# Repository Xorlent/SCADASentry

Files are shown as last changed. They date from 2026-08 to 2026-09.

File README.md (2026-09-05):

## SCADASentry - SCADA PLC Network Monitoring for the Rest of Us
### Ultra low-cost, no maintenance, purpose-built Allen Bradley ControlLogix PLC network and vulnerability monitor ###

> [!WARNING]
> _USE AT YOUR OWN RISK._  This solution is not recommended where a malfunction could carry injury, life, or financial risk.
> 
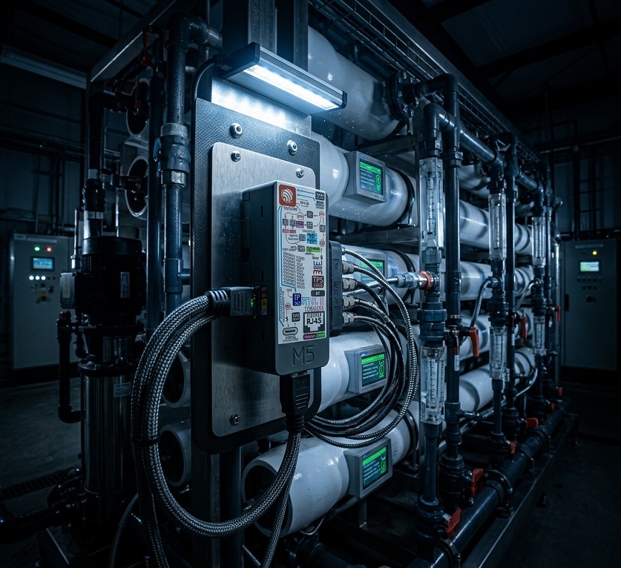
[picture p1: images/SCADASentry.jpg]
SCADASentry Sensor Image


## Table of Contents
- [Background](#background)
- [Features](#features)
- [Requirements](#requirements)
- [Functional Description](#functional-description)
  - [Activity monitoring](#activity-monitoring)
  - [EtherNet/IP monitoring](#ethernetip-monitoring)
  - [LAN device discovery](#lan-device-discovery)
  - [Minimizing PLC impact](#minimizing-plc-impact)
  - [Internet and DHCP detection](#internet-and-dhcp-detection)
- [Firmware Vulnerability Lookup](#firmware-vulnerability-lookup)
  - [How it works](#how-it-works)
  - [TXT record format](#txt-record-format)
  - [Example DNS TXT records](#example-dns-txt-records)
  - [Result](#result)
  - [When it runs](#when-it-runs)
- [Programming](#programming)
  - [Prepare configuration details for your device](#prepare-configuration-details-for-your-device)
  - [Configure and flash the device](#configure-and-flash-the-device)
- [SNMP Trap Reference](#snmp-trap-reference)
  - [LAN device discovery traps](#lan-device-discovery-traps)
  - [Device object varbinds](#device-object-varbinds)
  - [Enumerated varbinds (translated by the MIB)](#enumerated-varbinds-translated-by-the-mib)
- [Guidance and Notes](#guidance-and-notes)
- [Installation Options](#installation-options)
- [Technical Information](#technical-information)

## Background
Commercial OT/SCADA vulnerability and monitoring platforms are expensive to license, time-consuming to stand up, and finicky to keep running - and once they are running they tend to flood operators with unnecessary notifications that cause alert fatigue. For many, the cost and operational overhead can be hard to justify, especially in smaller environments.

SCADASentry takes a different approach. It is a purpose-built, ultra low-cost (~$21.50 in hardware), zero-maintenance device that plugs into a PoE port and quietly watches your PLC LAN. It reports only the events that matter: new or departed devices, run-key and firmware changes, and scanning/reconnaissance activity - All via standard SNMP traps or email.  No servers, specialized network appliances, span ports, agent software, cloud dependency, and no tuning required.

This device was designed specifically for monitoring Allen Bradley ControlLogix PLC network environments and is intentionally simple.  If detailed device activity (tag create/delete, program load, etc.) is needed, a commercial OT/SCADA platform is likely the better choice.

## Features
- **Passive honeypot monitoring**:
  Listens on any number of user-configurable TCP/UDP ports and ICMP types and reports every unexpected connection, revealing scanning, reconnaissance, and lateral movement that traditional tools miss.
- **EtherNet/IP discovery detection**:
  Watches UDP ports 44818 and 2222 for RSLogix/RSLinx browse traffic, flagging unauthorized devices attempting to discover and interact with your ControlLogix PLCs.
- **LAN device inventory**:
  Uses ARP to detect every device that joins or leaves the PLC network and identifies ControlLogix PLCs (vendor, firmware, serial, state, run-switch mode), so unapproved hardware is immediately visible.
- **Run-switch & firmware change alerts**:
  Continuously re-checks each PLC's run/remote/program mode and firmware revision and alerts on any change, so you immediately notice if a controller was left out of RUN after maintenance or a module was missed during a firmware update sweep.
- **Firmware vulnerability lookup**:
  Cross-references each CPU and communication module's firmware against DNS TXT records to flag controllers running firmware with known CVEs before they can be exploited.
- **Rogue DHCP / Internet detection**:
  Flags unexpected DHCP servers or Internet reachability on the PLC network, exposing rogue devices or a dangerous bridge between your OT network and the outside world.
- **Minimal PLC impact**:
  Sweeps with throttled ARP (never ICMP) and queries only the data it needs, keeping its footprint on the network and on production controllers as small as possible.
- **No-nonsense alerting**:
  Reports only the events that matter via standard SNMPv2c traps or email, integrating with your existing systems and reducing alert fatigue.
- **Ultra low-cost & zero-maintenance**:
  A ~$21.50 PoE device requiring no servers, span ports, agent software, cloud dependency, or tuning, making enterprise-grade OT monitoring practical even for smaller environments.

## Requirements
1. M5Stack [Unit-PoE-P4](https://shop.m5stack.com/products/unit-poe-with-esp32-p4), currently $21.50 USD
2. PoE network port or PoE power injector or a USB charger to power the device once deployed
3. USB-C cable for programming
4. An SNMP trap receiver (NMS such as PRTG) or an available SMTP relay
5. An accessible NTP server for time synchronization

## Functional Description
SCADASentry is a honeypot that listens on any number of user-configurable TCP and UDP ports and reports activity via **SNMPv2c traps** (or email via SMTP). It detects devices joining and leaving the local PLC LAN, alerts on scanning, reconnaissance, and lateral movement, and reports basic ControlLogix device information - notifying on run-key or firmware version changes.

### Activity monitoring
When unexpected activity is detected, the device immediately sends a trap or email containing the source IP, protocol, destination port (or ICMP type), and service name. The following events are reported:

| Event | Trap |
|---|---|
| TCP connection on a monitored port | `tcpConnectionTrap` |
| UDP packet on a monitored port | `udpConnectionTrap` |
| ICMP request of a monitored type | `icmpRequestTrap` |
| Fragmented IP packet (suspicious) | `ipFragmentTrap` |
| IP packet with options (suspicious) | `ipOptionsTrap` |
| Device comes online (boot or link recovery) | `deviceOnlineTrap` |

The device sends a `deviceOnlineTrap` when it boots (power recovery) or when its Ethernet link recovers, with a `honeypotStartReason` varbind distinguishing the cause (`powerOn` vs `linkUp`). It can also be configured to alert on ICMP ping requests (note: it will not respond to pings when ICMP monitoring is enabled).

### EtherNet/IP monitoring
For Rockwell Automation / EtherNet/IP broadcast traffic, the device listens on UDP ports **44818** and **2222** and reports only `ListIdentity` browse/discovery traffic, silently ignoring device I/O data. This detects RSLogix/RSLinx device browsing activity from unauthorized devices.

### LAN device discovery
The device periodically scans the local LAN using ARP to discover devices. For each discovered device it:

- Identifies ControlLogix PLCs via an EtherNet/IP `ListIdentity` broadcast, then queries them over TCP 44818 for identity, firmware, serial, state, and run-switch mode.
- Probes hosts that do not answer the `ListIdentity` broadcast directly on TCP 44818, so PLCs that suppress discovery responses are still identified.
- Reports newly discovered devices via `newDeviceDiscoveredTrap`, including the MAC address and the vendor, product name, firmware, serial, state, and run-switch mode if it is a PLC.
- Reports devices that stop responding via `deviceDisappearedTrap`. A departed device is detected only after its ARP entry expires, so this trap can lag a device's actual departure by up to 5 minutes.
- Re-checks the run-switch mode and firmware version of discovered PLCs periodically (configurable), reporting changes via `deviceModeChangedTrap` / `deviceFirmwareChangedTrap`.
- Enumerates the CPU and any Ethernet modules in the rack (including redundant/secondary CPUs) and derives an Advisory CVE search URL for each module.

### Minimizing PLC impact
SCADASentry is designed to be a passive observer of production PLCs, so it goes out of its way to avoid disturbing the controllers it monitors.

**No ICMP traffic.** Device discovery does not use ICMP echo requests (ping). Instead, the device sweeps the local subnet with ARP requests (`etharp_request`), which are answered by the network interface at the link layer and never touch a PLC's IP stack or CPU the way an ICMP echo would. Each host is probed with a single ARP request, and requests are throttled between hosts (`LAN_SCAN_ARP_THROTTLE_MS` in Config.h) to keep the scan's impact on the segment low.

**Only the data we need.** When querying a discovered PLC, the device reads only the CIP Identity object - product name, firmware revision, keyswitch position, serial number, and state - plus the Identity of each CPU and Ethernet module in the rack. Backplane slots are probed only up to the highest slot previously detected on each PLC, with a periodic full re-probe to catch modules added to higher slots (`SLOT_EXPANSION_CHECK_MULTIPLIER` in Config.h).

### Internet and DHCP detection
The device periodically probes the local LAN for a DHCP server and verifies Internet reachability:

- It retrieves the DHCP server identifier and the advertised default gateway, then tests Internet reachability through that gateway and/or the configured default gateway (a TCP connection to a public anycast IP on port 443, falling back to a DNS query to a public resolver).
- When Internet access is detected, it reports `internetDetectedTrap`, including the gateway and any DHCP server found.
- The DHCP probe sends only a DHCPDISCOVER, so it does not obtain or reserve an IP address - the device always keeps its statically-configured IP.
- If a DHCP server advertises a default gateway outside the device's configured subnet, the device treats it as a rogue DHCP server: it skips testing that gateway and reports `rogueDhcpServerTrap` (including the rogue server IP and the advertised gateway) instead.

## Firmware Vulnerability Lookup
SCADASentry can determine whether a discovered ControlLogix CPU or Ethernet module is running firmware with known vulnerabilities. It uses DNS TXT records, so it works using your own DNS infrastructure in a disconnected environment.

### How it works
1. For each module, the device extracts the full catalog suffix from the product name (e.g. `1756-EN2T/B` -> `EN2T/B`, `1756-L55/A` -> `L55/A`) and converts it to a valid DNS label (`/` becomes `-`, e.g. `EN2T/B` -> `EN2T-B`).
2. It prepends that label to `vulnSearchSuffix` (Config.h) to form the TXT record name, e.g. `EN2T-B.vuln.plc.local`.
3. It queries the configured DNS servers (`dns1`, then `dns2`) for a TXT record at that name.

### TXT record format
The TXT value is the **minimum firmware revision that is _not_ vulnerable**, formatted `major.minor` (e.g. `11.2`), or the literal string `EOL` (case-insensitive) for end-of-life products. For example, `EN2T-B.vuln.plc.local  TXT  "11.2"` marks any `1756-EN2T/B` running firmware older than `11.2` as vulnerable.

### Example DNS TXT records
The TXT record name is the module's full catalog suffix (with `/` replaced by `-`) prepended to `vulnSearchSuffix` in Config.h. For example, a `1756-EN2T/D` module (`EN2T/D` -> `EN2T-D`) with `vulnSearchSuffix = "vuln.plc.local"` resolves `EN2T-D.vuln.plc.local`. For CPUs whose product name has no catalog prefix (e.g. `ControlLogix 5580 Controller`), the short search term (`5580`) is used instead.

Starter records (the value is the minimum non-vulnerable firmware, or `EOL`):

| Label | TXT value | Module |
|---|---|---|
| `5580` | `37.013` | ControlLogix 5580 CPU |
| `L55-A` | `EOL` | 1756-L55 |
| `ENBT-A` | `EOL` | 1756-ENBT |
| `EN2T-A` | `EOL` | 1756-EN2T |
| `EN2T-B` | `EOL` | 1756-EN2T |
| `EN2T-C` | `EOL` | 1756-EN2T |
| `EN2T-D` | `12.002` | 1756-EN2T |
| `EN2F-A` | `EOL` | 1756-EN2F |
| `EN2F-B` | `EOL` | 1756-EN2F |
| `EN2F-C` | `12.002` | 1756-EN2F |
| `EN3TR-A` | `EOL` | 1756-EN3TR |
| `EN3TR-B` | `12.002` | 1756-EN3TR |
| `EN3TR-C` | `12.002` | 1756-EN3TR |

Each record's full name is `<label>.<vulnSearchSuffix>` (e.g. `EN2T-D.vuln.plc.local`). In a zone file:

```
EN2T-D.vuln.plc.local.  IN  TXT  "12.002"
L55-A.vuln.plc.local.   IN  TXT  "EOL"
```
Windows DNS Server example:  
[DNS Vulnerability DB](https://github.com/Xorlent/SCADASentry/blob/main/images/DNSVulnerabilityDB.png)
### Result
Each module is marked `YES` (vulnerable), `NO` (not vulnerable), or `N/A` (could not be determined):
- `YES` - firmware is below the published threshold, or the record is `EOL`.
- `NO` - firmware is at or above the published threshold.
- `N/A` - the DNS server was unreachable, or the feature is disabled (empty `vulnSearchSuffix` in Config.h).

When a lookup cannot be completed (no TXT record, DNS timeout, or an unparseable value), the module is conservatively treated as **vulnerable**.

### When it runs
- DNS availability is checked at the start of every LAN scan.
- Vulnerability status is evaluated when a device is first discovered and re-evaluated on every status check (`LAN_STATUS_CHECK_MULTIPLIER` in Config.h, default hourly), so newly published firmware TXT records are picked up automatically.

The per-module vulnerability status is reflected in email alerts - the firmware version is color-coded (green = `NO`, red = `YES`, black = `N/A`) and firmware-change emails use an `ALERT` subject when vulnerable, otherwise `Notice`. The status is also held in memory, like the advisory search URL.

## Programming
### Prepare configuration details for your device:  
- Host name
- Device IP address, gateway, and subnet mask
- Local DNS servers (recommended)
- Vulnerability lookup DNS search suffix (recommended)
- SNMP trap receiver IP and community string if email (USE_SMTP) is _false_ (default)
- Email to, from addresses, and SMTP relay IP if email (USE_SMTP) is _true_
- List of IP addresses (`excludedHosts` in Config.h) to exclude from the LAN scan and from honeypot alerting (traffic from these IPs does not generate alerts)
  - Example: RSLinx/FactoryTalk PC
- List of PLC IP addresses (`excludedPLCs` in Config.h) to exclude from ARP and EtherNet/IP discovery (these PLCs are not probed and not reported, even if they answer the `ListIdentity` broadcast)
- NTP server (required)
- TCP and/or UDP ports to listen on (defaults are recommended)
- LAN scan interval, slot expansion check interval, and hosts excluded from network scans (defaults are recommended)
### Configure and flash the device:
_Once you've successfully programmed a single unit, skip steps 1 & 2.  Repeating this process takes 3 minutes from start to finish._  
1. [Set up your Arduino programming environment](https://github.com/Xorlent/SCADASentry/blob/main/ARDUINO-SETUP.md)
2. In Arduino, open the project file (SCADASentry.ino)
   - Select Tools->Board->esp32 and select "ESP32P4 Dev Module"
   - Configure board settings according to the [Unit-PoE-P4 Board Configuration](https://github.com/Xorlent/SCADASentry/blob/main/images/ESP32P4-Config.jpg)
3. Connect the Unit-PoE-P4 to your computer via USB
   - Select Tools->Port and select the device port
     - If you're unsure, unplug the device, look at the port list, then plug it back in and select the new entry
> [!WARNING]
> Do not plug the device into a PoE-powered Ethernet port until after step 6 or you risk damaging your USB port!
4. In Arduino
   - Edit Config.h with configuration details you have collected for the device
   - Select Sketch->Upload to flash the device
   - When you see something similar to the following, proceed to step 5
```
Writing at 0x000f4830 [==============================] 100.0% 495157/495157 bytes... 
Wrote 935984 bytes (495157 compressed) at 0x00010000 in 3.6 seconds (2098.6 kbit/s).
Hash of data verified.

Hard resetting via RTS pin...
```
5. In Arduino
   - Select Tools->Serial Monitor
   - Address any configuration errors or warnings shown in the serial console
     - If you did not immediately open the serial monitor, you may need to re-connect the device to see the configuration check output
6. When configuration is complete, disconnect the USB cable
7. Connect the device to a PoE network port and mount as appropriate
8. If using SNMP (versus SMTP), configure your SNMP trap alerts:
    - Import SCADASENTRY-MIB.mib into your NMS to resolve trap OIDs to human-readable names
    - Add alert triggers based on traps received from the device to get immediate notice of potential scanning and lateral movement
    - Example trap for IP 10.70.103.12 connecting to TCP port 443:
      - Trap OID: 1.3.6.1.4.1.99999.0.1 (tcpConnectionTrap)
      - Varbinds: honeypotSourceIp=10.70.103.12, honeypotProtocol=6, honeypotDestPort=443, honeypotServiceName="https", honeypotEventTime="2026-08-16T21:12:52Z"
    - Example trap for IP 10.70.103.12 connecting to UDP port 137:
      - Trap OID: 1.3.6.1.4.1.99999.0.2 (udpConnectionTrap)
      - Varbinds: honeypotSourceIp=10.70.103.12, honeypotProtocol=17, honeypotDestPort=137, honeypotServiceName="netbios-ns"
    - Example trap for IP 10.70.103.12 sending a ping request to the honeypot:
      - Trap OID: 1.3.6.1.4.1.99999.0.3 (icmpRequestTrap)
      - Varbinds: honeypotSourceIp=10.70.103.12, honeypotProtocol=1, honeypotIcmpType=8, honeypotServiceName="echo-request"
## SNMP Trap Reference
All traps are SNMPv2c, sent to UDP port 162 (configurable). Import `SCADASENTRY-MIB.mib` into your NMS to resolve OIDs to human-readable names and translate enumerated values.

| Trap | OID | Varbinds |
|---|-----|---|
| `tcpConnectionTrap` | `1.3.6.1.4.1.99999.0.1` | eventTime, sourceIp, protocol, destPort, serviceName |
| `udpConnectionTrap` | `1.3.6.1.4.1.99999.0.2` | eventTime, sourceIp, protocol, destPort, serviceName |
| `icmpRequestTrap` | `1.3.6.1.4.1.99999.0.3` | eventTime, sourceIp, protocol, icmpType, serviceName |
| `ipFragmentTrap` | `1.3.6.1.4.1.99999.0.4` | eventTime, sourceIp, protocol, serviceName |
| `ipOptionsTrap` | `1.3.6.1.4.1.99999.0.5` | eventTime, sourceIp, protocol, serviceName |
| `deviceOnlineTrap` | `1.3.6.1.4.1.99999.0.6` | eventTime, sourceIp, startReason |

### LAN device discovery traps

| Trap | OID | Varbinds |
|---|-----|---|
| `newDeviceDiscoveredTrap` | `1.3.6.1.4.1.99999.0.8` | eventTime, deviceIp, deviceMac, (PLC: vendor, productName, firmware, serial, state, mode, and per-module slot/type/productName/firmware) |
| `deviceDisappearedTrap` | `1.3.6.1.4.1.99999.0.9` | eventTime, deviceIp, deviceMac |
| `deviceModeChangedTrap` | `1.3.6.1.4.1.99999.0.10` | eventTime, deviceIp, deviceMac, prevMode, mode |
| `deviceFirmwareChangedTrap` | `1.3.6.1.4.1.99999.0.11` | eventTime, deviceIp, deviceMac, moduleSlot, moduleType, moduleProductName, modulePreviousFirmware, moduleFirmware |
| `internetDetectedTrap` | `1.3.6.1.4.1.99999.0.12` | eventTime, gatewayIp, dhcpServerIp, internetAccessible, detectionMethod |
| `rogueDhcpServerTrap` | `1.3.6.1.4.1.99999.0.13` | eventTime, dhcpServerIp, gatewayIp |

Every trap also carries the standard `sysUpTime.0` (TimeTicks) and `snmpTrapOID.0` varbinds.

### Device object varbinds

| OID | Name | Type |
|-----|---|---|
| `.1.6.0` | `deviceIpAddress` | IpAddress |
| `.1.7.0` | `deviceMacAddress` | OCTET STRING (6) |
| `.1.8.0` | `deviceVendor` | INTEGER (CIP vendor ID) |
| `.1.9.0` | `deviceProductName` | OCTET STRING |
| `.1.10.0` | `deviceFirmwareVersion` | OCTET STRING |
| `.1.11.0` | `deviceSerial` | OCTET STRING |
| `.1.12.0` | `deviceState` | INTEGER (enum) |
| `.1.13.0` | `deviceMode` | INTEGER (enum) |
| `.1.15.0` | `devicePreviousMode` | INTEGER (enum) |
| `.1.21.0` | `internetDhcpServerIp` | IpAddress |
| `.1.22.0` | `internetAccessible` | INTEGER (enum) |
| `.1.23.0` | `internetDetectionMethod` | INTEGER (enum) |
| `.1.24.0` | `internetGatewayIp` | IpAddress |
| `.1.25.1.1` | `moduleIndex` | INTEGER |
| `.1.25.1.2` | `moduleSlot` | INTEGER (0 = CPU) |
| `.1.25.1.3` | `moduleType` | INTEGER (enum) |
| `.1.25.1.4` | `moduleProductName` | OCTET STRING |
| `.1.25.1.5` | `moduleFirmware` | OCTET STRING |
| `.1.25.1.6` | `modulePreviousFirmware` | OCTET STRING |

### Enumerated varbinds (translated by the MIB)

- `honeypotProtocol`: `icmp(1)`, `tcp(6)`, `udp(17)`
- `honeypotStartReason`: `powerOn(1)`, `linkUp(2)`
- `honeypotIcmpType`: `ping(8)`, `pingExtended(42)`
- `deviceState`: `nonexistent(0)`, `selfTesting(1)`, `standby(2)`, `operational(3)`, `majorRecoverableFault(4)`, `majorUnrecoverableFault(5)`, `communicationFault(6)`, `unconfigured(7)`
- `deviceMode`: `program(0)`, `run(1)`, `testRemote(2)`
- `moduleType`: `cpu(14)`, `ethernet(12)`
- `internetAccessible`: `no(0)`, `yes(1)`
- `internetDetectionMethod`: `none(0)`, `tcpConnect(1)`, `dnsQuery(2)`

## Guidance and Notes
- The device produces SNMPv2c traps on UDP port 162 (community string configurable in Config.h).
- SMTP alerts require an unauthenticated SMTP relay that is configured to allow the SCADASentry device IP address.
- TCP and UDP listening ports are fully user-configurable with no constraints.
- It is recommended you exempt the SCADASentry device IP addresses in any legitimate vulnerability or network scanners to avoid triggering honeypot alerts.
- If ICMP is disabled in Config.h, the device will respond to pings from any IP address within the routable network.
- LAN device discovery scans the local subnet using ARP, so it only sees devices on the same L2 segment.
- Pressing the button on the side of the Unit-PoE-P4 for > 1 second clears all detected-device and holdoff state, restarting detection as if the device had just booted.

## Installation Options
- You can find 3D printable DIN rail and 1RU mount options [here](https://github.com/Xorlent/SCADASentry/tree/main/3DModels)

## Technical Information
- CPU and Memory
  - 360MHz dual core + 40MHz LP core RISC-V
  - 768KBytes RAM
  - 16MBytes Flash + 32MBytes PSRAM
- Operating Specifications
  - Operating temperature: 0°F (-17.7°C) to 104°F (40°C)
  - Operating humidity: 5% to 90% (RH), non-condensing
- Power Consumption
  - 6W maximum via 802.3af Power-over-Ethernet
- Ethernet
  - IP101GRI or TLK110 PHY
  - 10/100 Mbit twisted pair copper
  - IEEE 802.3af Power-over-Ethernet

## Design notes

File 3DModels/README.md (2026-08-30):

## Printable DIN Rail SCADASentry Mount
### Parts Needed
- Qty. 1.25" Paper Clamp per each 2 SCADASentry mounts (each uses one clip handle)
- Qty. 1 3mm x 10mm pan head screw
- Qty. 1 M4 flathead screw (8mm recommended, up to 12mm will work)
- Qty. 1 M4 nut
### Assembly
- Print parts in the orientation shown below; add a 4-5 mm outer brim to the DIN clip only to prevent print failure
- Place the paper clamp handle into the DIN clip part, insert into the DIN mount, and secure with the 3mm x 10mm pan head screw
- Install the DIN base in the desired orientation (vertical or horizontal), insert the M4 screw and clamp the parts together with the M4 nut
- Slide the Unit-PoE-P4 module into the base, Ethernet port first and closest to the face of the base
- Install the mount by pulling back on the clip handle and clipping the mount onto the rail, pushing in the clip to secure the module

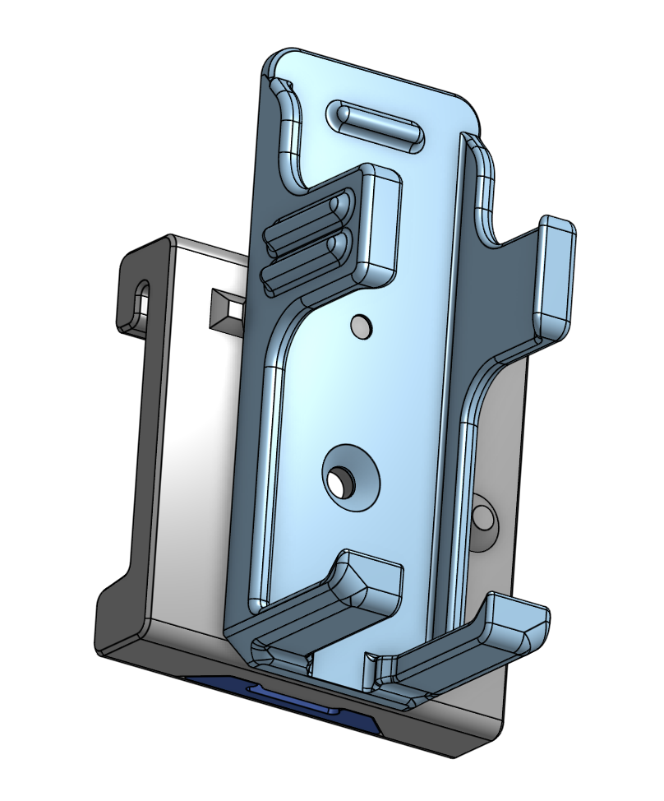
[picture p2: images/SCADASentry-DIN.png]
DIN Assembly

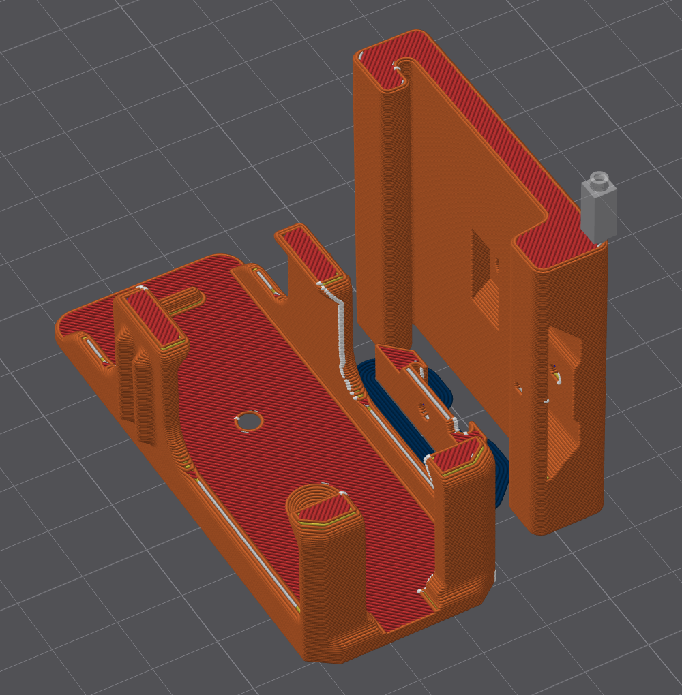
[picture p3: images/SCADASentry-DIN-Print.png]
DIN Print Orientation


## Printable 1RU Rackmount SCADASentry Base
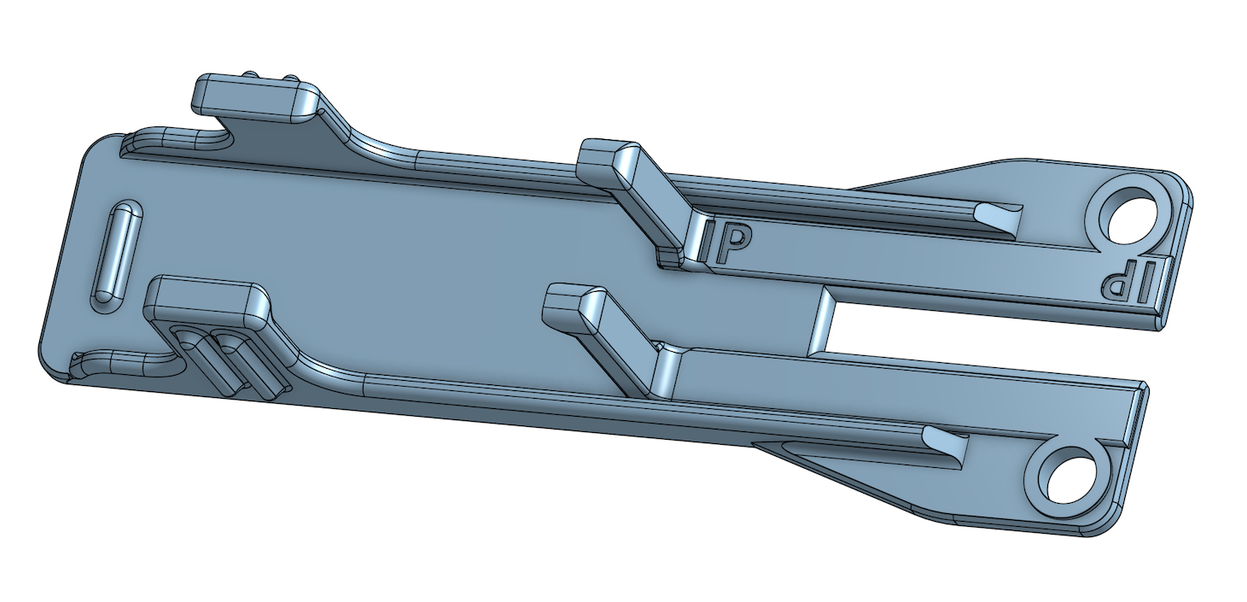
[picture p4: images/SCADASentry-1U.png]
1RU Rackmount Base Image


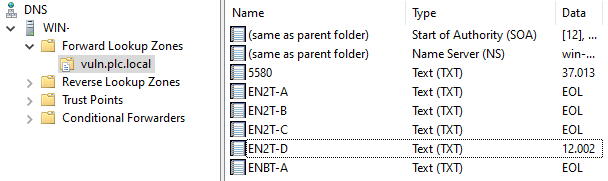
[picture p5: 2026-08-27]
images/DNSVulnerabilityDB.png

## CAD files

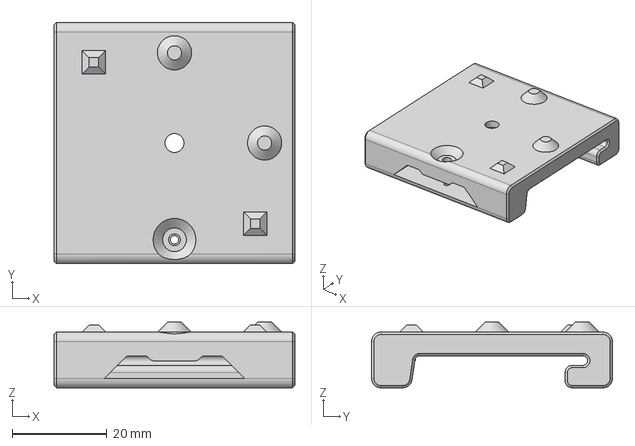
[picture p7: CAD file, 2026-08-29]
3DModels/SCADASentry-DINMount.step
50.8 x 50.8 x 13.8 mm

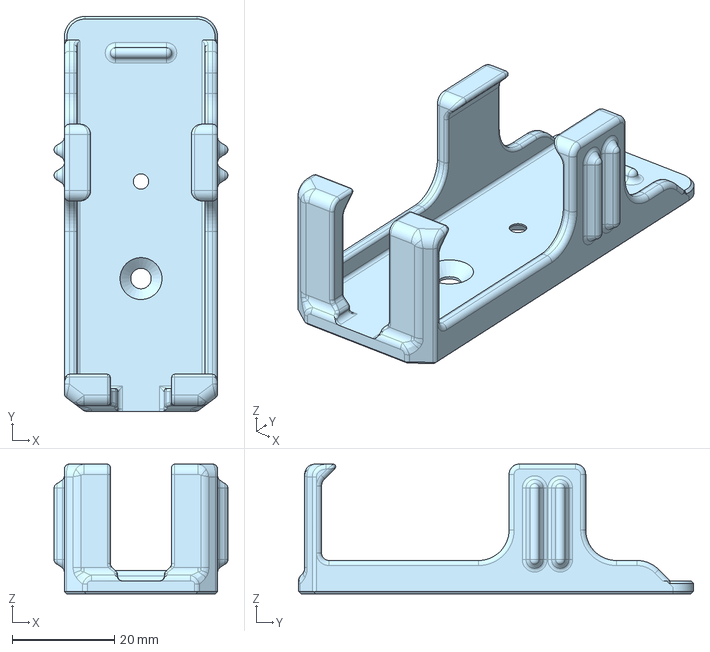
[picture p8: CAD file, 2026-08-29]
3DModels/SCADASentry-DINBase.step
34.0 x 77.3 x 25.4 mm

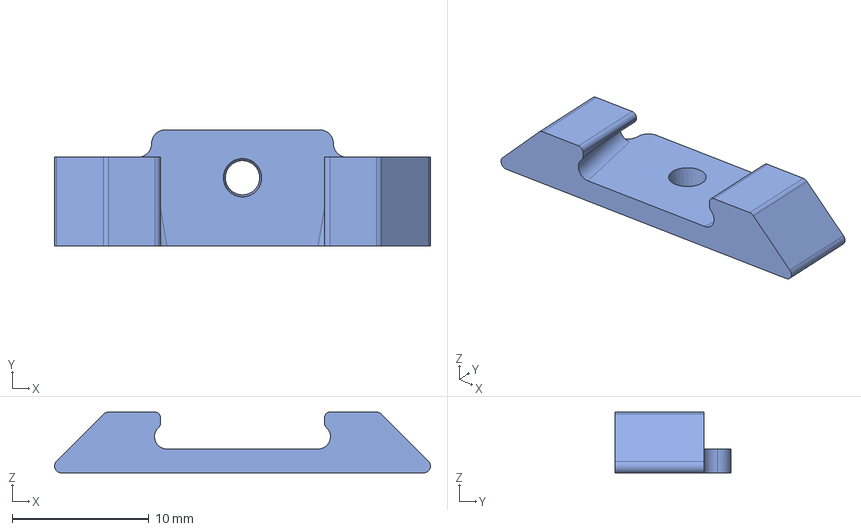
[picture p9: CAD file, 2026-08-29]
3DModels/SCADASentry-DINClip.step
27.5 x 8.50 x 4.45 mm

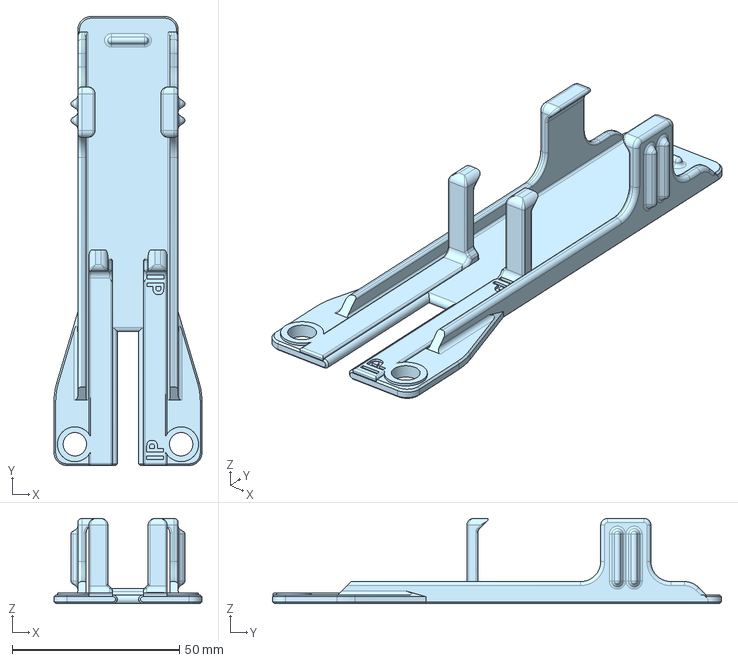
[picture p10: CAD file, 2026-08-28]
3DModels/SCADASentry-1U.step
44.2 x 134.1 x 25.4 mm

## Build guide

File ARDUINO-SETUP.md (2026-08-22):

1. Download the latest Arduino IDE appropriate for your operating system (https://www.arduino.cc/en/software)
2. Open the Arduino IDE
3. Close/save the Preferences window
4. Open the Boards Manager
   - Type "esp32" in the search field and select "esp32 by Espressif Systems" (__NOT "Arduino ESP32 Boards"__)
     - Install version 3.3.11
5. Open the Libraries Manager
   - Type "NTP" in the search field and select "NTP by Stefan Staub"
     - Install version 1.8.0

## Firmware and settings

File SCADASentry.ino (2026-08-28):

/*
 * SCADASentry.ino
 * 
 * USE AT YOUR OWN RISK. This solution is not recommended where a malfunction could carry injury, life, or financial risk.
 * 
 * GNU GENERAL PUBLIC LICENSE Version 3, 29 June 2007
 * https://github.com/Xorlent/SCADASentry
 * 
 * Raw Socket Implementation - Now monitors unlimited ports and ICMP types
 * Designed for M5Stack Unit-PoE-P4 or other device with sufficient resources
 * 
 * CONFIGURATION: All user-configurable settings are in Config.h
 * Edit Config.h to customize your honeypot deployment.
 */

#include "Config.h"

////////--------------------------------------- DO NOT EDIT ANYTHING BELOW THIS LINE ---------------------------------------////////

#include <ETH.h>
#include <WiFiUdp.h>
#include <NTP.h>
#include <lwip/ip.h>
#include <lwip/tcp.h>
#include <lwip/udp.h>
#include <lwip/icmp.h>
#include <lwip/raw.h>
#include <lwip/prot/tcp.h>
#include "HoneypotLogging.h"
#include "LanScanner.h"
#include "InternetDetection.h"
#include "ConfigValidation.h"

// Define TCP structures and flags if not already available
#ifndef TCPH_FLAGS
#define TCPH_FLAGS(phdr) (lwip_ntohs((phdr)->_hdrlen_rsvd_flags) & 0xFF)
#endif

#ifndef TCP_SYN
#define TCP_SYN   0x02U
#endif

#ifndef TCP_ACK
#define TCP_ACK   0x10U
#endif

// Map an IANA IP protocol number to the holdoff bucket (ProtocolType).
static ProtocolType protocolTypeFor(uint8_t ianaProtocol) {
  switch (ianaProtocol) {
    case IP_PROTO_UDP:  return PROTO_UDP;
    case IP_PROTO_ICMP: return PROTO_ICMP;
    case IP_PROTO_TCP:
    default:            return PROTO_TCP;
  }
}

#define ETH_ADDR        1
#define ETH_POWER_PIN   51
#define ETH_TYPE        ETH_PHY_TLK110
#define ETH_PHY_MDC     31
#define ETH_PHY_MDIO    52
#define ETH_CLK_MODE    EMAC_CLK_EXT_IN

// Reset button (GPIO 45, active-high: grounded when idle, 3.3V when pressed)
#define RESET_BUTTON_PIN            45
#define RESET_BUTTON_DEBOUNCE_MS    50
#define RESET_BUTTON_HOLD_MS        1000   // button must be held this long to reset

// Reset button debounce state
static int resetButtonState = LOW;          // stable (debounced) state
static int resetButtonLastReading = LOW;    // last raw reading
static unsigned long resetButtonLastDebounce = 0;
static unsigned long resetButtonPressedAt = 0;   // millis() when the button was first pressed
static bool resetButtonTriggered = false;         // true once the reset has fired for this press
static bool resetButtonArmed = false;             // false until the pin settles to idle after boot

////////---------------------------------------        Create runtime objects        ---------------------------------------////////

// Compile-time array size validation
static_assert(honeypotNumPorts <= 65535, "TCP port array exceeds maximum size");
static_assert(honeypotNumUDPPorts <= 65535, "UDP port array exceeds maximum size");
static_assert(honeypotNumICMPTypes <= 255, "ICMP type array exceeds maximum size");

// Port bitmaps for O(1) lookups (65536 ports = 8192 bytes each)
// Bit N set = port N is monitored
uint8_t tcpPortBitmap[8192];
uint8_t udpPortBitmap[8192];

// Set bit in bitmap (mark port as monitored)
inline void setBitInBitmap(uint8_t* bitmap, uint16_t port) {
  bitmap[port >> 3] |= (1 << (port & 0x07));
}

// Check if bit set in bitmap (is port monitored?)
inline bool isBitSetInBitmap(const uint8_t* bitmap, uint16_t port) {
  return (bitmap[port >> 3] & (1 << (port & 0x07))) != 0;
}

// SNMP trap and NTP clients
WiFiUDP snmpUdp;
NTP ntp(snmpUdp);

// Logging system
HoneypotLogging logger(hostName, ip, snmpTrapSvr, snmpTrapPort, snmpCommunity, DEBUG, 
                       TCP_HOLDOFF_SECONDS, UDP_HOLDOFF_SECONDS, ICMP_HOLDOFF_SECONDS,
                       &snmpUdp, &ntp,
                       USE_SMTP, smtpServer, smtpPort, smtpFromAddr, smtpToAddr);

// LAN scanner
LanScanner scanner(&logger, ip, gateway, subnet);
TaskHandle_t scannerTaskHandle = NULL;

// Internet access detection
InternetDetection internetDetector(&logger, gateway);
TaskHandle_t internetDetectionTaskHandle = NULL;

// LAN scanner task: periodically scans the local subnet for devices
void scannerTask(void* parameter) {
  // Wait briefly after boot for NTP sync and network settling
  vTaskDelay(5000 / portTICK_PERIOD_MS);
  while (1) {
    scanner.runScan();
    // Wait for the scan interval, or wake immediately on a reset notification.
    ulTaskNotifyTake(pdTRUE, (LAN_SCAN_INTERVAL_SECONDS * 1000) / portTICK_PERIOD_MS);
  }
}

// Internet detection task: periodically probes for a DHCP server and verifies
// Internet reachability to detect Internet access.
void internetDetectionTask(void* parameter) {
  // Wait after boot for NTP sync and network settling.
  vTaskDelay(10000 / portTICK_PERIOD_MS);
  while (1) {
    internetDetector.runDetection();
    vTaskDelay((INTERNET_DETECTION_INTERVAL_SECONDS * 1000) / portTICK_PERIOD_MS);
  }
}

// Raw sockets for packet capture (one per protocol)
struct raw_pcb *tcp_raw_socket;
struct raw_pcb *udp_raw_socket;
struct raw_pcb *icmp_raw_socket;

// NTP update tracking
unsigned long lastNTP = 0;

// Ethernet link state tracking (for linkUp notifications)
bool linkWasUp = false;

// Static string constants for suspicious traffic logging
static const char* const SUSPICIOUS_TCP_FRAGMENT = "TCP-fragment";
static const char* const SUSPICIOUS_UDP_FRAGMENT = "UDP-fragment";
static const char* const SUSPICIOUS_ICMP_FRAGMENT = "ICMP-fragment";
static const char* const SUSPICIOUS_UNKNOWN_FRAGMENT = "unknown-fragment";
static const char* const SUSPICIOUS_TCP_IP_OPTIONS = "TCP-ip-options";
static const char* const SUSPICIOUS_UDP_IP_OPTIONS = "UDP-ip-options";
static const char* const SUSPICIOUS_ICMP_IP_OPTIONS = "ICMP-ip-options";
static const char* const SUSPICIOUS_UNKNOWN_IP_OPTIONS = "unknown-ip-options";

// EtherNet/IP (Rockwell Automation) browse filtering
// On these UDP ports, only report ListIdentity (browse) traffic; ignore implicit I/O.
#define ENIP_LIST_IDENTITY_CMD 0x0063  // EtherNet/IP encapsulation command for ListIdentity (browse)
#define ENIP_PORT_44818 44818          // EtherNet/IP I/O + browse port
#define ENIP_PORT_2222 2222            // Legacy EtherNet/IP port (1756-ENET era)

////////---------------------------------------     End create runtime objects     ---------------------------------------////////

// Check if TCP port is monitored (O(1) bitmap lookup)
bool isHoneypotTCPPort(uint16_t port) {
  return isBitSetInBitmap(tcpPortBitmap, port);
}

// Get service name for TCP port
const char* getTCPServiceName(uint16_t port) {
  for(int i = 0; i < honeypotNumPorts; i++) {
    if(honeypotTCPPorts[i].port == port) {
      return (honeypotTCPPorts[i].service != NULL) ? honeypotTCPPorts[i].service : "unknown";
    }
  }
  return "unknown";
}

// Check if UDP port is monitored (O(1) bitmap lookup)
bool isHoneypotUDPPort(uint16_t port) {
  if (!MONITOR_UDP) return false;
  return isBitSetInBitmap(udpPortBitmap, port);
}

// Get service name for UDP port
const char* getUDPServiceName(uint16_t port) {
  if (!MONITOR_UDP) return "unknown";
  for(int i = 0; i < honeypotNumUDPPorts; i++) {
    if(honeypotUDPPorts[i].port == port) {
      return (honeypotUDPPorts[i].service != NULL) ? honeypotUDPPorts[i].service : "unknown";
    }
  }
  return "unknown";
}

// Check if ICMP type is monitored
bool isHoneypotICMPType(uint8_t type) {
  if (!MONITOR_ICMP) return false;
  for(int i = 0; i < honeypotNumICMPTypes; i++) {
    if(honeypotICMPTypes[i].type == type) {
      return true;
    }
  }
  return false;
}

// Get name for ICMP type
const char* getICMPTypeName(uint8_t type) {
  if (!MONITOR_ICMP) return "unknown";
  for(int i = 0; i < honeypotNumICMPTypes; i++) {
    if(honeypotICMPTypes[i].type == type) {
      return (honeypotICMPTypes[i].name != NULL) ? honeypotICMPTypes[i].name : "unknown";
    }
  }
  return "unknown";
}

// Get fragment description string for protocol
static const char* getFragmentDescription(u8_t protocol) {
  switch(protocol) {
    case IP_PROTO_TCP:  return SUSPICIOUS_TCP_FRAGMENT;
    case IP_PROTO_UDP:  return SUSPICIOUS_UDP_FRAGMENT;
    case IP_PROTO_ICMP: return SUSPICIOUS_ICMP_FRAGMENT;
    default:            return SUSPICIOUS_UNKNOWN_FRAGMENT;
  }
}

// Get IP options description string for protocol
static const char* getIPOptionsDescription(u8_t protocol) {
  switch(protocol) {
    case IP_PROTO_TCP:  return SUSPICIOUS_TCP_IP_OPTIONS;
    case IP_PROTO_UDP:  return SUSPICIOUS_UDP_IP_OPTIONS;
    case IP_PROTO_ICMP: return SUSPICIOUS_ICMP_IP_OPTIONS;
    default:            return SUSPICIOUS_UNKNOWN_IP_OPTIONS;
  }
}

// Update NTP if 10 minutes elapsed
void updateNTPIfNeeded() {
  unsigned long currentMillis = millis();
  if(currentMillis - lastNTP >= 600000) {
    if(ntp.update()) {
      lastNTP = currentMillis;
    }
  }
}

// Validate IP header, return IP header length or 0 if invalid
static u8_t validateIPHeader(struct pbuf *p, struct ip_hdr **iphdr_out) {
  // Validate packet size
  if (p == NULL || p->tot_len < sizeof(struct ip_hdr)) {
    return 0;
  }
  
  // Ensure header in first pbuf (prevents buffer overrun)
  if (p->len < sizeof(struct ip_hdr)) {
    return 0;
  }
  
  struct ip_hdr *iphdr = (struct ip_hdr *)p->payload;
  
  // Validate header length (20-60 bytes)
  u8_t ip_header_len = IPH_HL(iphdr) * 4;
  if (ip_header_len < 20 || ip_header_len > 60 || p->tot_len < ip_header_len) {
    return 0;
  }
  
  // Ensure entire header (with options) in first pbuf
  if (p->len < ip_header_len) {
    return 0;
  }
  
  *iphdr_out = iphdr;
  return ip_header_len;
}

// Raw packet receive callback (all protocols)
static u8_t raw_recv_callback(void *arg, struct raw_pcb *pcb, struct pbuf *p, const ip_addr_t *addr) {
  // Validate packet
  struct ip_hdr *iphdr;
  u8_t ip_header_len = validateIPHeader(p, &iphdr);
  
  if (ip_header_len == 0) {
    if (p != NULL) pbuf_free(p);
    return 1;
  }
  
  // Detect IP fragmentation (suspicious)
  // Offset in 8-byte units, non-zero = fragmented
  u16_t fragment_offset = (lwip_ntohs(IPH_OFFSET(iphdr)) & IP_OFFMASK) * 8;
  u16_t ip_flags = lwip_ntohs(IPH_OFFSET(iphdr)) & 0xE000;
  bool more_fragments = (ip_flags & IP_MF) != 0;
  bool is_fragment = (fragment_offset > 0) || more_fragments;
  
  if (is_fragment) {
    // Log fragmented packet (suspicious)
    uint32_t sourceIPAddr = ip4_addr_get_u32(&iphdr->src);
    u8_t protocol = IPH_PROTO(iphdr);
    
    const char* fragDesc = getFragmentDescription(protocol);
    
    logger.enqueueLogEvent(EVT_FRAGMENT, 0, sourceIPAddr, protocolTypeFor(protocol), protocol, fragDesc);
    
    // Drop fragmented packets
    pbuf_free(p);
    return 1;
  }
  
  // Detect IP options (suspicious)
  // Options rarely used; often indicates attacks or manipulation
  if (ip_header_len > 20) {
    // Log IP options (suspicious)
    uint32_t sourceIPAddr = ip4_addr_get_u32(&iphdr->src);
    u8_t protocol = IPH_PROTO(iphdr);
    
    const char* optDesc = getIPOptionsDescription(protocol);
    
    logger.enqueueLogEvent(EVT_IP_OPTIONS, 0, sourceIPAddr, protocolTypeFor(protocol), protocol, optDesc);
    
    // Drop packets with IP options
    pbuf_free(p);
    return 1;
  }
  
  u8_t protocol = IPH_PROTO(iphdr);
  
  // Handle TCP
  if (protocol == IP_PROTO_TCP) {
    // Validate TCP header size
    if (p->tot_len < ip_header_len + sizeof(struct tcp_hdr)) {
      pbuf_free(p);
      return 1;
    }
    
    // Ensure TCP header in first pbuf (not fragmented across pbufs)
    if (p->len < ip_header_len + sizeof(struct tcp_hdr)) {
      pbuf_free(p);
      return 1;
    }
    
    // Get TCP header
    struct tcp_hdr *tcphdr = (struct tcp_hdr *)((u8_t *)p->payload + ip_header_len);
    
    // Extract destination port
    uint16_t dest_port = ntohs(tcphdr->dest);
    
    // Check for SYN without ACK (new connection)
    u8_t flags = TCPH_FLAGS(tcphdr);
    bool is_syn = (flags & TCP_SYN) != 0;
    bool is_ack = (flags & TCP_ACK) != 0;
    
    if (is_syn && !is_ack) {
      // Check if port is monitored
      if (isHoneypotTCPPort(dest_port)) {
        // Extract source IP
        uint32_t sourceIPAddr = ip4_addr_get_u32(&iphdr->src);
        
        // Enqueue event for main loop processing
        // Filtering (broadcast/multicast/holdoff) happens in main loop
        logger.enqueueLogEvent(EVT_TCP_CONN, dest_port, sourceIPAddr, PROTO_TCP, IP_PROTO_TCP, getTCPServiceName(dest_port));
      }
      // Consume the SYN so the honeypot does not answer the connection attempt
      pbuf_free(p);
      return 1;
    }
    // Not a pure SYN (SYN-ACK, ACK, data, FIN, RST, ...) - let the normal TCP
    // stack handle it so outgoing connections (e.g. EtherNet/IP to a PLC) work.
    return 0;
  }
  
  // Handle UDP
  else if (protocol == IP_PROTO_UDP && MONITOR_UDP) {
    // Validate UDP header size
    if (p->tot_len < ip_header_len + sizeof(struct udp_hdr)) {
      pbuf_free(p);
      return 1;
    }
    
    // Ensure UDP header in first pbuf (not fragmented)
    if (p->len < ip_header_len + sizeof(struct udp_hdr)) {
      pbuf_free(p);
      return 1;
    }
    
    // Get UDP header
    struct udp_hdr *udphdr = (struct udp_hdr *)((u8_t *)p->payload + ip_header_len);
    
    // Extract destination port
    uint16_t dest_port = ntohs(udphdr->dest);
    
    // Check if port is monitored
    if (isHoneypotUDPPort(dest_port)) {
      // For EtherNet/IP ports, only report ListIdentity (browse) traffic;
      // ignore implicit I/O data (which lacks the 0x0063 command).
      if (dest_port == ENIP_PORT_44818 || dest_port == ENIP_PORT_2222) {
        // Ensure at least 4 bytes of UDP payload are in the first pbuf
        // (encapsulation Command + Length fields)
        if (p->len < ip_header_len + sizeof(struct udp_hdr) + 4) {
          pbuf_free(p);
          return 1;
        }
        // Read the EtherNet/IP encapsulation Command field (first 2 bytes, little-endian).
        // NOTE: ControlLogixDiscovery.cpp reads/writes this header little-endian and
        // works against real PLCs, so the on-wire order is little-endian here too.
        const u8_t* payload = (const u8_t*)p->payload + ip_header_len + sizeof(struct udp_hdr);
        uint16_t command = payload[0] | (payload[1] << 8);
        if (command != ENIP_LIST_IDENTITY_CMD) {
          pbuf_free(p);
          return 1;  // Not a browse request; ignore I/O traffic
        }
        // A ListIdentity RESPONSE (Length > 0) answers our own discovery
        // broadcast; pass it through to the normal UDP stack so the
        // ControlLogixDiscovery client can receive it. A ListIdentity
        // REQUEST (Length == 0) is browse traffic from another device,
        // which we log and consume below.
        uint16_t encapLength = payload[2] | (payload[3] << 8);
        if (encapLength > 0) {
          return 0;  // pass through (do NOT free the pbuf)
        }
      }
      
      // Extract source IP
      uint32_t sourceIPAddr = ip4_addr_get_u32(&iphdr->src);
      
      // Enqueue event for main loop processing
      // Filtering (broadcast/multicast/holdoff) happens in main loop
      logger.enqueueLogEvent(EVT_UDP_CONN, dest_port, sourceIPAddr, PROTO_UDP, IP_PROTO_UDP, getUDPServiceName(dest_port));
      
      // Consume the monitored-port packet
      pbuf_free(p);
      return 1;
    }
    
    // Not a monitored port: pass through so legitimate UDP traffic
    // (e.g. NTP responses on the NTP client's ephemeral port) reaches the
    // normal UDP stack.
    return 0;
  }
  
  // Handle ICMP
  else if (protocol == IP_PROTO_ICMP && MONITOR_ICMP) {
    // Validate ICMP header size
    if (p->tot_len < ip_header_len + sizeof(struct icmp_echo_hdr)) {
      pbuf_free(p);
      return 1;
    }
    
    // Ensure ICMP header in first pbuf (not fragmented)
    if (p->len < ip_header_len + sizeof(struct icmp_echo_hdr)) {
      pbuf_free(p);
      return 1;
    }
    
    // Extract ICMP type
    struct icmp_echo_hdr *icmphdr = (struct icmp_echo_hdr *)((u8_t *)p->payload + ip_header_len);
    u8_t icmp_type = ICMPH_TYPE(icmphdr);
    
    // Check if ICMP type is monitored
    if (isHoneypotICMPType(icmp_type)) {
      // Extract source IP
      uint32_t sourceIPAddr = ip4_addr_get_u32(&iphdr->src);
      
      // Enqueue event for main loop processing
      // Filtering (broadcast/multicast/holdoff) happens in main loop
      logger.enqueueLogEvent(EVT_ICMP_REQ, icmp_type, sourceIPAddr, PROTO_ICMP, IP_PROTO_ICMP, getICMPTypeName(icmp_type));
    }
  }
  
  pbuf_free(p);
  
  // Return 1 = packet consumed and freed
  return 1;
}
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
void loop() {
  // Check the reset button
  checkResetButton();

  // Process queued log events from lwIP task
  logger.processLogQueue(ip, subnet);
  
  // Update NTP if needed
  updateNTPIfNeeded();
  
  // Monitor Ethernet link for linkUp events
  bool linkUp = ETH.linkUp();
  if (linkUp && !linkWasUp) {
    // Link just recovered after being down
    logger.sendDeviceOnlineTrap(ONLINE_REASON_LINK);
  }
  linkWasUp = linkUp;
  
  delay(1);
}

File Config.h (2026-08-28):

/*
 * Config.h
 * 
 * USE AT YOUR OWN RISK. This solution is not recommended where a malfunction could carry injury, life, or financial risk.
 * 
 * Configuration settings for SCADASentry
 * Edit the values in this file to customize your honeypot deployment
 * 
 * GNU GENERAL PUBLIC LICENSE Version 3, 29 June 2007
 * https://github.com/Xorlent/SCADASentry
 */

#ifndef CONFIG_H
#define CONFIG_H

#include <IPAddress.h>

// Port and service name structure for TCP/UDP monitoring
struct HoneypotPort {
  uint16_t port;
  const char* service;
};

// ICMP type and name structure for monitoring
struct HoneypotICMPType {
  uint8_t type;
  const char* name;
};

// Debug mode - enables verbose serial output showing events and SNMP trap messages
const bool DEBUG = true;

////////------------------------------------------- CONFIGURATION SETTINGS AREA --------------------------------------------////////

////////// Network Configuration //////////

    // Device Identification
    const uint8_t hostName[] = "SCADASentry"; // Set hostname, no spaces, no domain name per RFC 3164

    // Ethernet configuration:
    const IPAddress ip(192, 168, 1, 50);        // Set device IP address.
    const IPAddress gateway(192, 168, 1, 1);    // Set default gateway IP address.
    const IPAddress subnet(255, 255, 255, 0);    // Set network subnet mask.
    const IPAddress dns1(192, 168, 1, 5);            // Primary DNS
    const IPAddress dns2(192, 168, 1, 6);    // Secondary DNS

    // DNS search suffix for firmware vulnerability lookups. The module catalog
    // name (e.g. "EN2T-B") is prepended to this suffix to form the TXT record
    // name queried from the DNS servers above (e.g. "EN2T-B.vuln.example.com").
    // Do not include a leading dot. Leave empty to disable vulnerability lookups.
    const char* const vulnSearchSuffix = "vuln.plc.local";

    // Whether to send firmware-change notifications for modules that are NOT
    // vulnerable (isVulnerable = "NO"). When false (default), firmware-change
    // emails/traps are suppressed for non-vulnerable modules; vulnerable ("YES")
    // and unknown ("N/A") modules are always reported.
    const bool notifyNotVulnerable = false;

    // Logging method configuration:
    // Choose logging method: true = SMTP relay, false = SNMP trap
    const bool USE_SMTP = false;

    // SNMP trap configuration (used when USE_SMTP = false):
    const IPAddress snmpTrapSvr(192, 168, 1, 2); // Set SNMP trap receiver (NMS) IP address.
    const uint16_t snmpTrapPort = 162;      // Set SNMP trap receiver UDP port.
    const char* const snmpCommunity = "public"; // SNMPv2c community string.

    // SMTP relay configuration (used when USE_SMTP = true):
    const IPAddress smtpServer(192, 168, 1, 25); // SMTP relay server IP address
    const uint16_t smtpPort = 25;          // SMTP relay port (usually 25)
    const char* const smtpFromAddr = "honeypot@example.com";  // From email address
    const char* const smtpToAddr = "security@example.com";    // To email address

    // NTP server configuration:
    // Select your NTP server info by configuring and uncommenting ONLY ONE line below:
    const IPAddress ntpSvr(192, 168, 1, 2);    // Set internal NTP server IP address.
    //const char* const ntpSvr = "pool.ntp.org";   // Or set a NTP DNS server hostname.

    // IP addresses to exclude from the LAN scan (in addition to this device's
    // network address, broadcast address, and default gateway, which are
    // always skipped). These addresses are also excluded from honeypot
    // alerting: traffic with any of these IPs as the source will not generate
    // honeypot alerts.
    const IPAddress excludedHosts[] = {
        // IPAddress(192, 168, 1, 10),  // example: Authorized RSLogix/FactoryTalk PC
    };

    // PLC IP addresses to exclude from ARP and EtherNet/IP discovery. Unlike
    // excludedHosts, these are also ignored if they answer the ListIdentity
    // broadcast: they are not probed and not reported as discovered devices.
    const IPAddress excludedPLCs[] = {
        // IPAddress(192, 168, 1, 20),  // example: Life safety PLC
    };

////////// Monitoring Configuration (Defaults Recommended) //////////

////////// TCP Port Monitoring //////////

    const HoneypotPort honeypotTCPPorts[] = {
        {22, "ssh"}, {23, "telnet"}, {80, "http"}, {102, "siemens-s7"}, 
        {502, "modbus"}, {2222, "rockwell-csp2"}, {3389, "rdp"}, {4840, "opcua"}, {20000, "dnp3"}, 
        {44818, "rockwell-encap"}, {47808, "bacnet"}, {18245, "ge-srtp"}, {18246, "ge-srtp"}, 
        {34962, "profinet"}, {34964, "profinet"}, {34980, "profinet"}, {28784, "automationdirect"}
    };

////////// UDP Port Monitoring //////////

    // Enable UDP monitoring
    const bool MONITOR_UDP = true;

    // Common OT/SCADA UDP ports:
    const HoneypotPort honeypotUDPPorts[] = {
        {502, "modbus"}, {2222, "rockwell-browse"}, {4840, "opcua"}, {20000, "dnp3"}, {44818, "rslogix-browse"}
    };
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

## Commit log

2026-08-18 Add ARP throttle time constant to Config.h
    Added a constant for ARP discovery request throttle time.
2026-08-18 Implement delay between ARP discovery requests
    Added a delay to throttle ARP discovery requests.
2026-08-18 Add SMTP alerts for device detection/state changes
2026-08-18 Reduce maximum tracked IPs and increase max devices
2026-08-18 Clarify SMTP alerts and honeypot IP references
    Updated references to honeypot IP addresses to SCADASentry device IP addresses for clarity.
2026-08-18 Revise SCADASentry README for clarity and details
    Updated the functional description and configuration details for SCADASentry, clarifying alert mechanisms and device capabilities.
2026-08-19 Reduce maximum number of LAN devices from 253 to 252
2026-08-27 Revise requirements for device power options
    Updated requirements section to include PoE options and reordering.
2026-08-27 Fix wording in device description for clarity
    Corrected the description of the device's purpose and features.
2026-08-28 Update README to clarify power requirements
2026-08-28 Update README for button press instructions
2026-08-29 Enhance README with parts and assembly details
    Added parts list and assembly instructions for the Printable DIN Rail SCADASentry Mount.
2026-08-29 Update assembly instructions for DIN clip brim
    Clarified instructions for adding a brim to the DIN clip during printing.
2026-08-30 Clarify paper clamp usage in README
2026-08-30 Update installation instructions in README.md
    Added instructions for installing the Unit-PoE-P4 module and securing the mount.
2026-10-09 Memory optimization
    Move devices[] device info array buffer into PSRAM. Fallback to DRAM
2026-10-23 Headless operation, cleanup, add'l TCP scan detection
    - Removed the `while (!Serial)` boot gate (user-applied); device boots without USB.
    - Rogue DHCP: cleaned up rogue gateway detection.
    - TCP scan detection: NULL/FIN/XMAS and invalid flags are reported via
    `tcpConnectionTrap` (`honeypotTcpFlags` varbind) and consumed. ACK scans out of scope.
    - Updated docs and MIB
